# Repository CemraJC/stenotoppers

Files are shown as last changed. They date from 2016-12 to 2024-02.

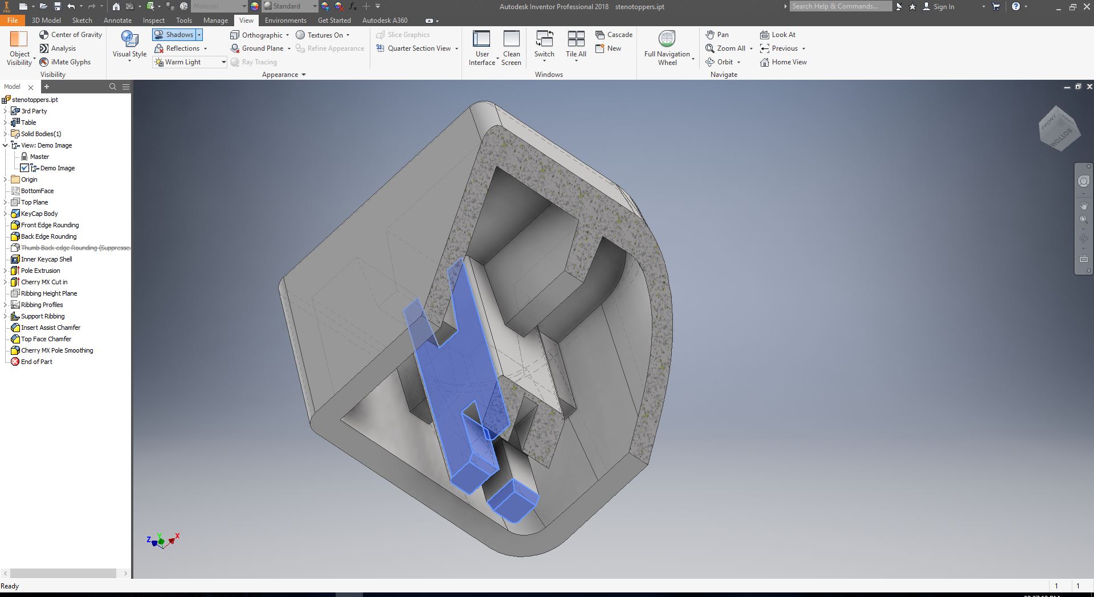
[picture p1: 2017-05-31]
images/autodesk-inventor-editing-demo.jpg

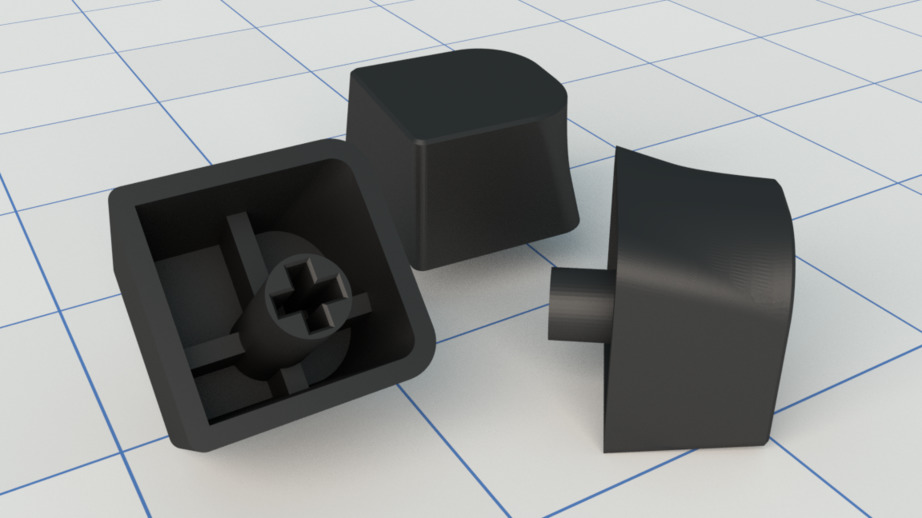
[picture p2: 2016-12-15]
images/stenotopper-closeup.jpg

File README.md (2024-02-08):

# StenoToppers

> Convert your keyboard into a stenotype!  
> *Version 1.2.0*

Demonstration of StenoToppers (Render)

## [Get them from the releases page!](https://github.com/CemraJC/stenotoppers/releases)

## Hall of Fame

[Visit the hall of fame!](https://github.com/CemraJC/stenotoppers/wiki/StenoToppers-Hall-of-Fame) Submit your own prints through the Issues tab, or by editing the Wiki directly!

## *Update*

The StenoToppers keycap set now includes number bar (numbar) keys (since version 1.1.0). These keys are much like normal keys, but they fit on the same level as the StenoToppers and sit nice and close together.

Two additional print assemblies have been made available - one for just the numbar keys, and another for the full set *including* the numbar keys.

### Preface

This repository contains the 3D design files for the "StenoToppers", including and [a detailed CAD drawing][cad-pdf] and 3D models. The branch "[generic-models][generic-branch]" has files (in STL format) that should work with any proper 3D modeling software (such as [AutoDesk 123D][123d-editor] or [Blender][blender]). This branch (master) contains the part files and assemblies for [AutoDesk Inventor 2016][inventor], from which the STL files are derived.

Note that StenoToppers are designed for use with a mechanical keyboard that supports [N-key rollover (NKRO)][nkey], alongside the fantastic open source [Plover][plover] software. If you're interested in learning more about *typing at the speed of thought*, see the [Plover Blog][plover-blog]. 

**If it all seems too hard:**<br> 
3D model and printing work is currently fiddly and time consuming. If you want a quicker solution that is guaranteed to work on any steno-ready keyboard, then we heartily recommend the [Laser-Cut Keytoppers][keytoppers] ($20 USD + $Shipping) from the [Plover Store][plover-store]<sup>[1](#not-a-sponsor)</sup>. These are secured to existing keycaps with some sturdy "adhesive foam" and are reportedly easy to set up.

It is left as an excercise to bored DIY steno-enthusiasts to design and manufacture injection-moulded parts, which will inherently fit better and feel lighter.

**If it all seems too easy:**<br>
As this is an open source project, you are very welcome (and encouraged) to make and sell StenoToppers by your own means, under the terms of the license. In short, just make sure clients are aware that the project is open source and that they retain the same freedom to use this project as you do.

Anyway, on with the show.

## What are StenoToppers?

StenoToppers are a set of custom 3D printed keycaps which convert a mechanical keyboard into a stenotype look-alike. They are designed to fit any keyboard with Cherry MX keyswitches or any "identical" Cherry MX clone. 

The whole point of these keycaps is to slightly raise, compact and align the top two rows of keys (making it easier to chord them) and move the thumb-keys comfortably above the space-bar and into a more ergonomic position. Without StenoToppers, it is harder to press two keys with one finger and thumbs can become *very* sore trying to avoid the spacebar all the time.

Demonstration of StenoToppers (Real)

### A Note on Key Spacing

Notice how StenoToppers make the keys look a fair bit wider than normal keycaps. This is because StenoToppers utilize almost the entire keycap base to allow multiple keys to be pressed at once. On a QWERTY keyboard, pressing multiple keys at once is often undesirable, so keycaps heavily taper off to provide substantial space around them - too much space for speedy stenography. 

Also, note that although they line up horizontally (ortholinear), your keyboard is likely to have a non-standard slope angle to the base. This means that and keys are likely to be _vertically_ offset by two millimeters, and may collide. This shouldn't affect stenography in any noticeable way once [fitted properly][fitting-guide].

Top down of StenoToppers

For more detailed dimensions and specifications, check out the [drawing PDF][cad-pdf].

### Types of StenoToppers

Note that there are *four* variants of the keycap: standard, large, small and thumb. The standard keycaps are in majority and line up most of the top row's keys. The small and large variants are meant to go on the end of each row (in the right place, of course) so the rows match up with existing keys that are still staggered (like enter and tab). The small and large variants are required so the end of each row fits, but if the keyboard is otherwise empty of keys, they are optional. Thumb keys have no offset on the keycap stem, so they will fit in straight up-and-down.

# How to get StenoToppers

StenoToppers **are 3D printed items.** If you are lucky enough to have access to a 3D printer, then you can likely print these off yourself for very little cost. For the rest of us normal people, online services like [Shapeways][shapeways-store] and [Sculpteo][sculpteo] can print the models for you, albeit at a much higher cost. For even *more* money, you could even get them done in [nylon][shapeways-nylon] or [steel][shapeways-steel]! 

The models have been prepared on [Shapeways][shapeways-store], in the "Logical Store".

*Note: Try to avoid super expensive materials. The ABS and PLA materials are verified on home printers, but things like steel or aluminium are not verified to fit. See the [fitting guide][fitting-guide] for more information.*

# Printing

Printable models are available from the [generic-models][generic-branch] branch. All released versions can also be downloaded directly from the [project website][project-website] or the [Github Releases Page][github-releases].

### Print Stats:

| Full Print  | |
| :---: | :--: |
| Bounding box (Machine Space) | 130mm x 100mm x 20mm (208cm<sup>3</sup>) |
| Print mass | ~53g |
| Print material volume | ~51cm<sup>3</sup> |
| Print filament length | ~7.6m |
| Average Time | ~11.5 hours (at normal quality) | 
| Average material cost | $3 (assuming $50 for a 1kg reel) |
| Shapeways cost | Strong and Flexible, White: $60<br>Strong and Flexible, Black: $61 |

| Test Print  | |
| :---: | :--: |
| Bounding box (Machine Space) | 62mm x 40mm x 20mm (49cm<sup>3</sup>) |
| Print mass | ~10g |
| Print material volume | ~9.6cm<sup>3</sup> |
| Print filament length | ~1.4m |
| Average Time | ~3.2 hours | 
| Average material cost | 60 cents |

| Single Keycap  | |
| :---: | :--: |
| Bounding box (Machine Space) | 130mm x 100mm x 20mm (208cm<sup>3</sup>) |
| Print mass | ~2g |
| Print material volume | ~1.9cm<sup>3</sup> |
| Print filament length | ~28 cm |
| Average Time | ~40 mins | 
| Average material cost | 12 cents (i.e. Negligible) |

### Custom Keycap Sets

Sometimes, the "final" and "test" pre-compiled packages aren't what you're looking for. If, for example, you want to print a set of 350 standard keys (not sure why) then you'll need to make a custom assembly. If you're unfamiliar with 3D printing or 3D modelling, this may seem like a difficult task, however with tools such as [AutoDesk Meshmixer][meshmixer] or [Meshlab][meshlab] this task is relatively easy. When you download the models, you will have access to the individual keycap models. For a full keyboard, you should be printing **2 large, 2 small, 4 thumb and 18 standard stenotoppers**.

There are guides on how to merge STL files all over the place. Here is just a couple:

* [Meshmixer: Combining Models](http://www.instructables.com/id/Meshmixer-Combining-Models/)
* [Merging STL Files](https://edditiveblog.wordpress.com/2015/01/02/merging-stl-files/)
* [Editing and merging STL files. How-to and an offer. Any interest?](https://groups.google.com/forum/#!topic/inmoov/k4kzPOrsuzs)

### Pre-print checklist

<input type="checkbox"> Line width is close to (or less than) 0.5mm
<input type="checkbox"> Layer height is close to (or less than) 0.3mm
<input type="checkbox"> Printing with the top of the keycap(s) facing the print bed
<input type="checkbox"> Using a raft to avoid "elephant's foot"
<input type="checkbox"> Using 60% infill or above (for final-quality print)
<input type="checkbox"> Have at least 9m of filament on the spool.

### Minimum 3D Printer Specs

* Min Print bed size: 130mm x 100mm x 20mm for full print
    - Theoretically, you could make do with a 20mm x 20mm x 20mm if you were willing to do multiple prints.
* Max Layer height (for a good-quality print): 200 microns (0.2mm)
* Max Extrusion width: 500 microns (0.5mm) - aim for lower (0.4 or 0.3)

### An Important Note on Clearances

Because the Cherry MX stem is a standard size, it is important that the keycaps are printed so they fit snugly. For this reason, proper printer calibration is very important. Keyboards may vary, but ideally they will have the same key spacing and stem dimensions.

It's more complex than it sounds to get true-to-model dimensions, because different printers have varying tolerances (i.e. the printer will affect how much the printed object is different from the model). This is because things shrink as they cool. Some printers change their cooling settings or do over-extrusion in an attempt to correct this. These factors mean that a feature of the model can potentially end up smaller (rarely larger) in the print than it was in the 3D model. For tight fits like the Cherry MX stem, this contraction actually stops the keycap from fitting on the stem. 

All that is to say that an improperly calibrated printer has some consequences for this kind of model. Overall, you should expect to make minor adjustments to your printer to make sure it's printing true-to-model. 

If you don't want to muck around with your printer, then never fear - see the [fitting guide][fitting-guide] for ways to get the StenoToppers properly mounted on your keyboard.

## Model Customization (Advanced, optional)

The models are designed to be customized easily. Luckily, the majority of keyboards are designed to have a standard layout and spacing - so typists have consistency - which means that the default models *should* work fine, although you should definitely *do a test print* before printing all 26 keycaps.

Because the StenoToppers were designed in AutoDesk Inventor, we recommend using Inventor to modify them for your keyboard as well. See [this document][inventor-customization] for a very brief tutorial.

Demonstration image of Editing the 3D model with AutoDesk Inventor

However, for normal people who do not have access to software such as
AutoDesk Inventor, there are '.stl' models available for use in free modeling programs such as [AutoDesk 123D][123d-editor], [Blender][blender] or [MeshLab][meshlab]. Please see the "[generic-models][generic-branch]" branch for these. You will need to search for specific instructions on how to use your chosen mesh editor in order to edit the models. Obviously, if you customize a keycap, you will need to make your own print assembly.

Unfortunately, editing STL files can be a pain - especially when you need precision. If you have any suggestions for how to make the project more editable, be sure to open an issue on Github.

Demonstration image of Editing the 3D model with Blender

## A Word On Financial Contributions

The StenoToppers project does not accept voluntary financial support directly. Instead, all financial contributions towards this project should be made out to the [Open Steno Project][plover-donate]. Note that the StenoToppers team is not in any way affiliated with Plover or the Open Steno Project - it is simply that without them, StenoToppers would not have any reason to exist.

[Click for the Plover project donation page][plover-donate]

## Footnotes

[<a href="#not-a-sponsor">1</a>]: The StenoToppers team has no affiliation with any of the 3rd party projects or services mentioned in this document.

<!-- Link table, sorted by category -->

[inventor]:http://www.autodesk.com.au/products/inventor/overview
[inventor-customization]:https://github.com/CemraJC/stenotoppers/blob/master/docs/Customization%20with%20Inventor.md
[blender]: https://www.blender.org/download/
[123d-editor]: http://www.123dapp.com/design
[meshlab]: https://sourceforge.net/projects/meshlab/
[meshmixer]: http://www.meshmixer.com/

[fitting-guide]: https://github.com/CemraJC/stenotoppers/blob/master/FITTING-GUIDE.md

[generic-branch]: https://github.com/CemraJC/stenotoppers/tree/generic-models
[project-website]: https://cemrajc.github.io/stenotoppers/
[github-releases]: https://github.com/CemraJC/stenotoppers/releases
[cad-pdf]:https://github.com/CemraJC/stenotoppers/blob/master/drawings/base-keycap_cherrymx.pdf

[plover]: http://stenoknight.com/wiki/Getting_Started#Installing_Plover
[plover-blog]: http://plover.stenoknight.com/
[plover-store]: http://plover.deco-craft.com/
[plover-donate]: https://www.openstenoproject.org/donate/
[keytoppers]: http://plover.deco-craft.com/shop/view_product/Laser-Cut-Steno-Keys-Kit
[nkey]: https://en.wikipedia.org/wiki/Rollover_(key)

[sculpteo]: https://www.sculpteo.com/en/
[shapeways]: http://www.shapeways.com/
[shapeways-store]: https://www.shapeways.com/shops/logical-store?section=Stenography+and+Plover&s=0
[shapeways-steel]: http://www.shapeways.com/materials/steel
[shapeways-nylon]: http://www.shapeways.com/materials/strong-and-flexible-plastic

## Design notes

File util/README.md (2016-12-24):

This directory contains a script to run MeshLab server on a directory of STL files. The MeshLab script (.mlx) cleans and decimates (simplifies) the parts making them smaller and easier to handle.

Use only if you have MeshLab installed and are generating STL files. You will also need a Linux CLI.

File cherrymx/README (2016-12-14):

This folder contains models designed for the Cherry MX keyswitch design.
Note that these models are also suitable for Cherry MX variants (such as kailh).

For printing, please see the 'generic-models' branch of this repository.

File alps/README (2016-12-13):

This folder would contains models adapted for the ALPS keyswitch design.

Note that these models, although potentially useful, do not yet exist because
it was decided that Cherry MX switches are more common. Regardless, if a serious
need for ALPS switch variants of the StenoToppers arises, then the models will
go here.

This project is structured to allow for addition of alternative
keyswitch affixing systems.

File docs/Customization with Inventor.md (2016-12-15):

# Customizing the StenoToppers with AutoDesk Inventor

It is very easy to adjust key dimensions of the StenoToppers if you have access to AutoDesk Inventor. All the dimensions (parameters) are linked to the top-level "parameters.xlsx" file, so simply follow these steps to change one:

* Open the "parmeters.xlsx" file
* Find the parameter you want to change (they are clearly marked / described)
* Change it to your desired value (note that changing something too much may cause problems with the model, so modify only within reason)
* Save the spreadsheet
* Open the "stenotoppers.ipt" file in the "cherrymx" directory, using Inventor
* Navigate to `Manage > Parameters Panel > Parameters` (looks like *f<sub>x</sub>*) 
* With the parameters window open, click the "Update" button on the 2nd bottom row. The model should change to reflect your modification of the spreadsheet.
* If everything looks normal, close the parameters window and the spreadsheet.
* Export each iPart variant to STL format (see below)

### Exporting to STL

The StenoToppers model is what Inventor calls an "iPart", although you may have heard them called "Factory models" or "Factory parts". See [this tutorial][TFI-tutorial-iparts] for more information on iParts.

Because the model is an iPart, some custom code was needed to export each variant to STL. 

[TFI-tutorial-iparts]:link

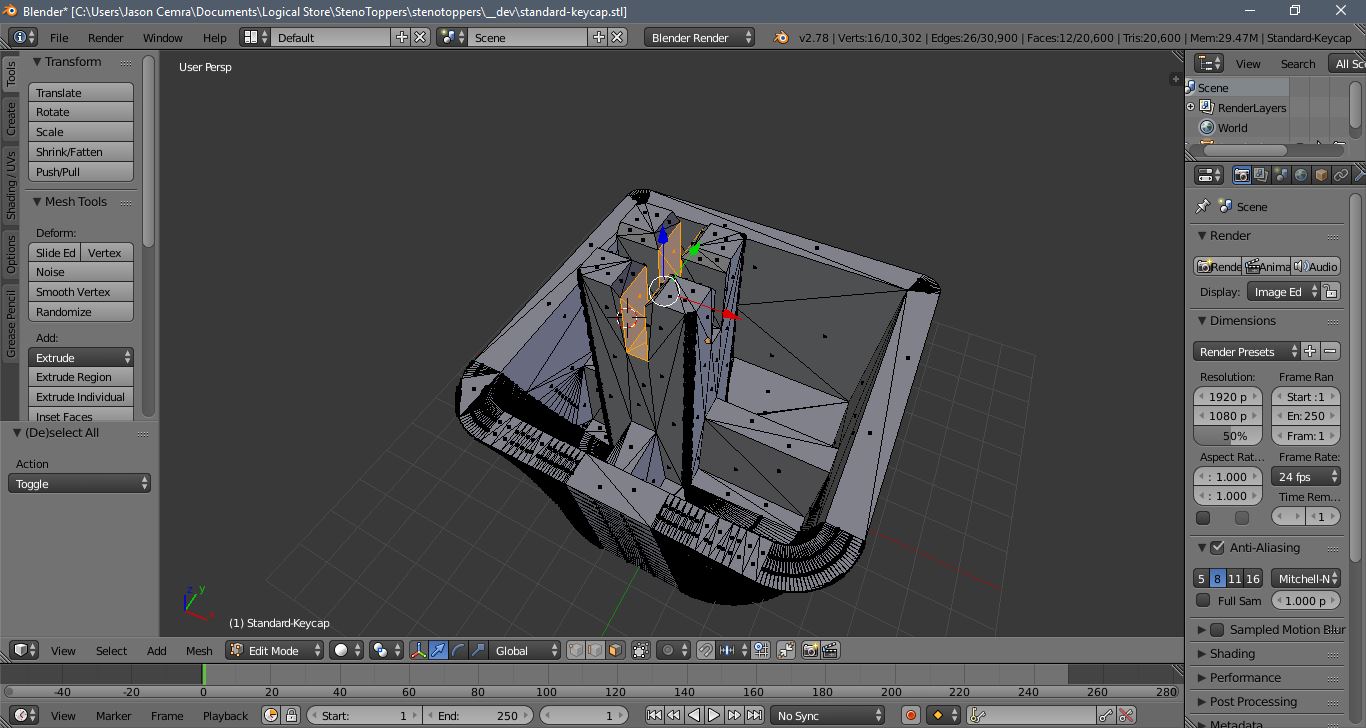
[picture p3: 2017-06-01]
images/blender-editing-demo.jpg

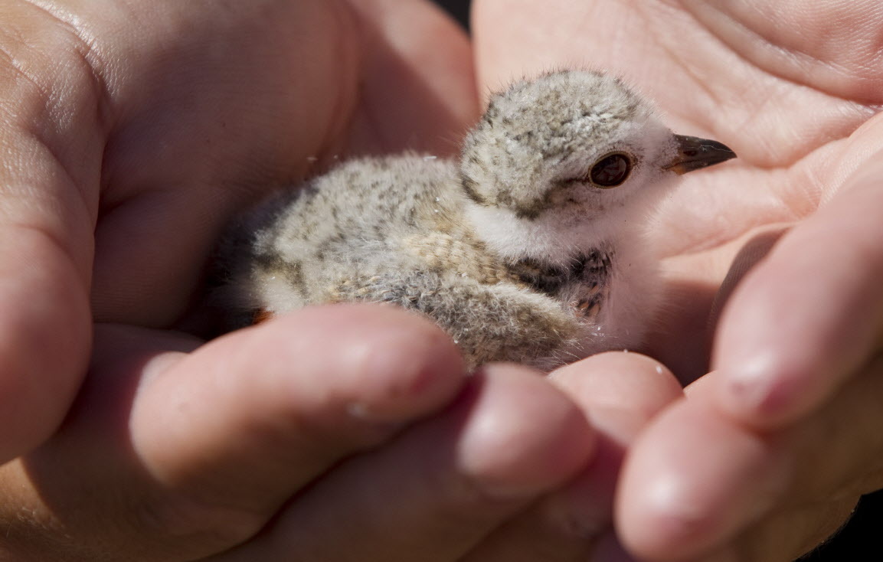
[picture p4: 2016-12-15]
images/plover-donate-image.jpg

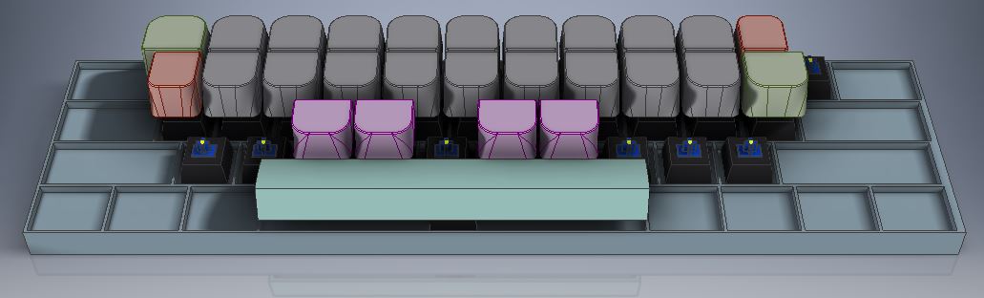
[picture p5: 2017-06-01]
images/stenotopper-demo-image.jpg

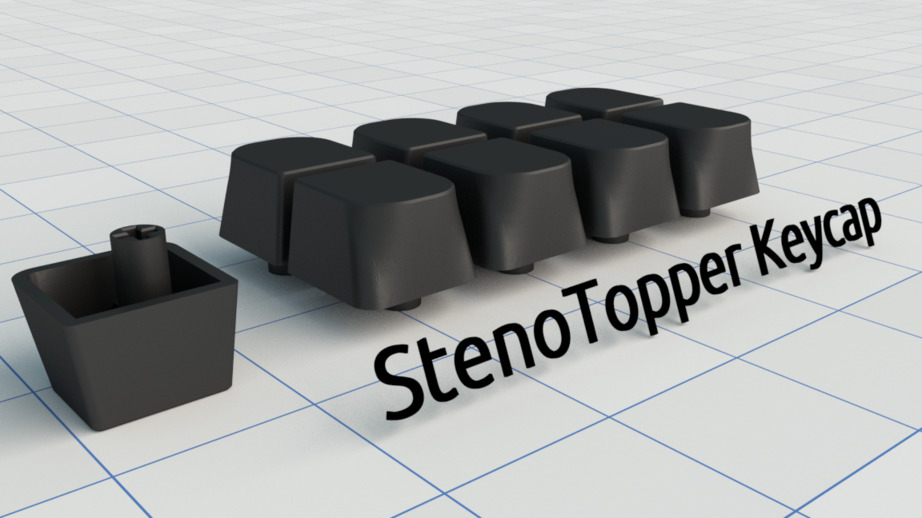
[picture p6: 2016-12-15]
images/stenotopper-render.jpg

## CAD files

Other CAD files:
drawings/stenotoppers_dimension_annotated.dwg
cherrymx/mockup-parts/cherry-mx-switch/keyswitch-base_cherrymx.ipt
cherrymx/mockup-parts/cherry-mx-switch/keyswitch-pole_cherrymx.ipt
cherrymx/mockup-parts/cherry-mx-switch/keyswitch_cherrymx.iam
cherrymx/mockup-parts/keyboard-base_standard.ipt
cherrymx/mockup-parts/keyboard-mockup_cherrymx.iam
cherrymx/mockup-parts/populated-keyboard_cherrymx.iam
cherrymx/mockup-parts/spacebar-keycap_mockup_cherrymx.ipt
cherrymx/print-assemblies/final-print-(with_numbar).iam
cherrymx/print-assemblies/final-print.iam
cherrymx/print-assemblies/numbar-print.iam
cherrymx/print-assemblies/test-print.iam
cherrymx/stenotoppers.ipt
cherrymx/stenotoppers/larger_cmx.ipt
cherrymx/stenotoppers/numbar_cmx.ipt
cherrymx/stenotoppers/smaller_cmx.ipt
cherrymx/stenotoppers/standard_cmx.ipt
cherrymx/stenotoppers/thumb_cmx.ipt
drawings/base-keycap_cherrymx.idw

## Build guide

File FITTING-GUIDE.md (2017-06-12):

# StenoToppers Fitting Guide

**Warning:** This project is not for the impatient. If you try to rush through the fitting process, you may end up breaking somthing. Although, since you're into steno, I imagine you like doing things the right way. I can assure you, StenoToppers are the "right way" to do DIY steno :wink:.

So grab a some fine wine and put on your favourite classical music. Depending on the quality of your print, the full fitting could take anywhere between 2 and 5 hours. The printer I had access to was pretty rubbish, so I believe this fitting guide covers the worst-case scenario quite well. Chances are good that your print will come out nicely.

When StenoToppers come out of the printer, they will likely not fit on your keyboard straight away. Straight off the printer, they look like this:

Messy StenoToppers

If you look closely, there's all sorts of garbage clogging up the connection mechanism:

Closeup of StenoTopper mess

If the printer isn't perfectly calibrated, and you're using a material or printing method that leaves a lot of residue behind, then there's going to be some cleanup to do. This guide is all about how you can get your StenoToppers from the images above to look like this:

Clean StenoToppers

## What you'll need

#### Needle File

You need a *very* fine needle file to clean up the stem. You should be able to get some of these cheaply if you don't already have them. Also, check to see if your friends can lend you any.

**Important:** If you have access to a Dremel (hand-held rotary bit tool), then I would highly recommend using it with a griding wheel rather than a file. Just be careful not to damage the key.

Needle files

#### Craft Knife

Just something with a sturdy blade. There's going to probably be bits of excess material on the upper part of the stem that makes the key stick if you try to press it on an angle. A knife will clean it up quicker than a file.

Craft Knife

#### Sticky Tape

Preferably high-quality. You may need this to make the key surface smooth (rather than the stepped finish from the printer). A smooth surface dramatically decreases the effects of interference.

Sticky Tape

#### Key Puller

You need to remove the existing keycaps from your keyboard. My keyboard came with the one below. I highly recommend using one of these, because trying to remove standard keycaps with fingers or a knife generally ends up with things being broken. A key-puller *may* not work with the StenoToppers, because they are much wider. They are tall enough, however, that you should be able to grip them with your hands.

Key Puller

## Procedure

For each key, you're doing the same basic thing: Cleaning and fitting. There's three basic things that, when done properly, will complete the fit and finish of the key.

1. Remove excess stem material
2. Fit keycap to a keyswitch
3. Make required surfaces smooth

**Important note:** If you're going to be doing this with needle files, I recommend that you spread the work out over a few days - to avoid your hands cramping up. I did all the filing in one hit (roughly 3 hours), and it took a further hour for my hands to fully recover.

With that out of the way, I'll go through each step for a standard stenotopper, and you can follow it for the rest.

### 1. Remove excess stem material

To get rid of the garbage the printer left behind, there's two main techniques. For the big stuff, you can try (gently) scraping it off with a craft knife:

Using knife for rough removal

Be sure to cut away from yourself, or use a grip that gives you *very* tight control over the blade. It's easy to slip on small parts like this.

Once the big stuff is removed, you'll likely need to use a needle file to clean up the inside of the stem and under the key:

Using file for clean up

Make sure you also target any waste on the *outside* of the stem, because this can affect how smoothly the key operates. It's hard to see, but if you feel it catch on the way down, then you probably just need to file down the outer faces.

Inner-waste highlighted

### 2. Fit keycap to a keyswitch

First, pull a keycap off your keyboard (use a key-puller please) and try to fit the stenotopper. Chances are, it won't fit. Don't force it - just take it off and do a *tiny* bit of filing on the inside. Remember, it only takes a difference of about 0.4 mm to go from too-tight to just-right. Be patient, you'll get the hang of it.

If you have removed all the waste material, the key should fit snugly and press in without catching - at any angle. If you use your finger to wobble the key around, it shouldn't move much more than 5 mm in any direction.

There may be a *tiny* gap between the top of the inside of the stem, and the top of the keyswitch. This is normal, and is meant to provide a bit of extra material in case the print comes out a bit off.

Front close up on switch

### 3. Make required surfaces smooth

When pressing the keys down, they will deflect a bit and probably rub against the key behind it (if there is one). This is expected, and will likely occur if your keyboard has an angled backplane. The solution is quite simple - just put some tape across the back of the key, to make it smooth.

Applying Sticky Tape

Sanding the back of the key is also an option, but this takes a fair bit more time - especially considering how many keys there are.

## And you're done!

Top down view

Once you have repeated the process for each key, you will have a full set of StenoToppers. Set aside about 5 hours to do this - it takes a while, but it's worth it for a comfortable DIY stenotype.

You may notice that the keys feel a bit heavier than normal. This is a by-product of the thickness of 3D printed parts and is unavoidable without using different manufacturing techniques. Personally, I like the heavier feel. It makes the keys seem like they're solid, and *really* doing something. Sort of like a heavy watch. Of course, your mileage may vary with this.

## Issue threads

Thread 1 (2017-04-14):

ready for standard use?

gabrielqv, 2017-04-14:
So when do you think the project will reach 1.00, didn't find any info of why you said it was not recommend for use yet.

CemraJC, 2017-06-01:
Sorry things are taking so long - there were many problems with shipping test parts over (mostly courier mishandling or lost in post).  I have only just received the final test print, and am working on the final release documentation.

You should expect the final release within 2 weeks.

Closed 2017-06-03.

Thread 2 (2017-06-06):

Generate smaller STL files that will print faster?

ddrscott, 2017-06-06:
Is it possible to generate smaller sets of STI files? My local library has a 6 hour print maximum.
Maybe group by left and and right and final?
I don't have Autodesk Inventor to attempt it myself.

Thanks

CemraJC, 2017-06-12:
Fear not! You do not need AutoDesk Inventor to do this.

As you are aware, there are individual STL files provided for each type of keycap. If, I assume, you want to be sending two print jobs to the printer to stay under the 6 hour maximum, then I would recommend using software such as [AutoDesk Meshmixer](http://www.meshmixer.com/download.html) or [meshlab](http://www.meshlab.net/) to merge the single-keycap STLs into each job as you desire.

As this is quite a specific scenario, hopefully you can understand why I would like you to do this yourself. In short order, I will add a section to the Readme with my above comments, for future users.

Closed 2017-06-17.

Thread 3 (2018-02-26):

Orthographic layout

brennenawana, 2018-02-26:
Would be great to have stenotoppers made for orthographic keyboard layouts like the Plank. I guess that would basically mean removing the staggered offset. Great work, thanks so much!

CemraJC, 2018-03-01:
Not a bad idea! I might get around to making a variation of the existing models, should be easy enough. I'll put it on my long-term todo list for now.

wrongPaul, 2018-04-25:
I literally just came here to open the same issue, has anyone made any progress on this? If not (or possibly even if they have) I'll start working on porting these over

nadavwr, 2020-10-10:
Maybe we can just print thumb toppers only for all fingers? I tried to give a closer look at the 3d model, and seems to me like the north-facing side is a bit more slanted (making chording a bit harder)—am I imagining this?

AndersonTorres, 2020-12-08:
Another one!

I bought an ortholinear keyboard and I would like to try steno on it.

designbybeck, 2020-12-08:
Very nice Anderson, I'm a newbie as well. Only started following this
project because I was interested in plover and steno stuff and wanted to
look into making my own.

On Mon, Dec 7, 2020 at 10:08 PM Anderson Torres <notifications@github.com>
wrote:

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

canuckkat, 2021-07-26:
> Not a bad idea! I might get around to making a variation of the existing models, should be easy enough. I'll put it on my long-term todo list for now.

Any luck on porting them over? I wish I knew enough to help. :(

BoxingLaunch, 2022-01-31:
Has anyone made any progress on this? Would love some ortho keycaps!

AndersonTorres, 2022-01-31:
Maybe I should talk with a CAD guru or something like.

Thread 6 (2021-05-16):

My Stenotopper Setup

JeffersonDing, 2021-05-16:
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

CemraJC, 2021-06-16:
Hey man, that's awesome!

I'll add you to the hall of fame.

I'll leave this "issue" open, so if anyone else stumbles across this, they can [find the link to the hall of fame](https://github.com/CemraJC/stenotoppers/wiki/StenoToppers-Hall-of-Fame).

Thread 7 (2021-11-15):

Stenotoppers and POM Jellies

DrMeiji, 2021-11-15:
Here is my board with the stenotoppers installed, printed at my university's library. The board is a GK64X with gateron black switches and strawberry POM jelly alpha numerals.

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

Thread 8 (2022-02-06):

My StenoTopper set - Just learning

RunningUtes, 2022-02-06:
Just thought I would modify the STL file and create a StenoTopper for learning. Printed on a Prusa MK3s in 4h.
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

I modified the stl file so there was no need to file the keys. They went on the key switches straight off the printer.

CemraJC, 2023-02-27:
Looks awesome!

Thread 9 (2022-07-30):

Stems snapping

FrocketGaming, 2022-07-30:
Curious if I'm doing something wrong on the standard prints for these. Printed two at .15mm and both of them had the stem legs flair out and snap off when trying to install onto halo clears and gateron yellows.

I really want to use these on the board I'm building.

Monniasza, 2023-07-24:
I've had this issue too at #12

Monniasza, 2023-08-17:
Here are improved keycaps at Thingiverse:
Older design:  https://www.thingiverse.com/thing:3167887
Newer design: https://www.thingiverse.com/thing:3208321

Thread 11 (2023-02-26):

Feature request: More accessible option.

Roskott, 2023-02-26:
[Solid Steonotoppers.zip](https://github.com/CemraJC/stenotoppers/files/10834360/Solid.Steonotoppers.zip)

This is what I did to make the Toppers so that I can pull them on and off without much issue, thus not having to devote my daily driver keyboard to existing solely for plover, or have to slowly pull and replace the keycaps to more easily use the program.

Each key sits on top of a cherry mx keycap, a loose amount of string runs through all four rows, loose enough to not interfere with the key presses, but enough that the entire lot can be pulled off all at once without much issue. To keep each of the keys seated properly on the keycaps, a small amount of silicone was spread around the inner lip of the cherry keycap portion to act as a nonslip surface to keep the keys from sliding or popping off at release of the key.

To slice these on SuperSlicer I enabled the Arachne perimeters. I used a negative volume cube with each of the keys to hollow out the existing stem, and reduce the weight. 2 2mmx30mm negative volume cylinders were used parallel to the xy plane intersecting at the midpoint of the cherry key stem to facilitate the string.

I am very new to 3d drafting, so this is little more than 3 models stuck together, but it is a start. I noticed that the keys that are to be placed on the qwerty row are far more stable than the others, for the numbar this was a simple matter of turning them 180deg around, but all keys on the asdf row as well as the vowel keys would need to be reworked. I am working on that now, as well as making it so that the print head will not be printing onto nothingness. for several layers.

My set are being printed into PETG with a 0.4 nozzle at 0.24 layer height.

Now would be a good time to also say that you should look around at your local libraries to see if they have access to a 3d printer. I promise it will be significantly cheaper than the Shapeways method, and most libraries with exhaustively work towards helping you get to where you need to be with this skill.

Version0.2 of this idea will rectify "newbie" model issues
Version0.3 will reduce the height and thus material
Version0.4 will hopefully be a more elegant final version someone will find useful.

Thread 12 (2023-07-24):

Issue with stems

Monniasza, 2023-07-24:
The stems in StenoToppers are fragile, unlike mass produced keycaps. I've alredy broken several keycaps due to this flaw
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

On the top is a mass produced Strike Battle Spectra keycap, on the bottom a StenoTopper. Notice how the StenoTopper does not cover the switch stem fully, but the default keycaps do.

CemraJC, 2024-02-08:
Unfortunately that's a limitation of the design - there's as much plastic in there as possible, but if there was any more (or a surrounds) then it makes the walls too thin and they're difficult to print.

3D printers have gotten a lot better than when the keycaps were originally designed, so potentially reducing the layer height and using PETG could help? If you or someone else can come up with a design that manages to make a slot surrounds (a la OEM keycap) and still fit the tolerance of the manufacturing process, then I'll happily merge a PR for it!

Closed 2024-02-08.

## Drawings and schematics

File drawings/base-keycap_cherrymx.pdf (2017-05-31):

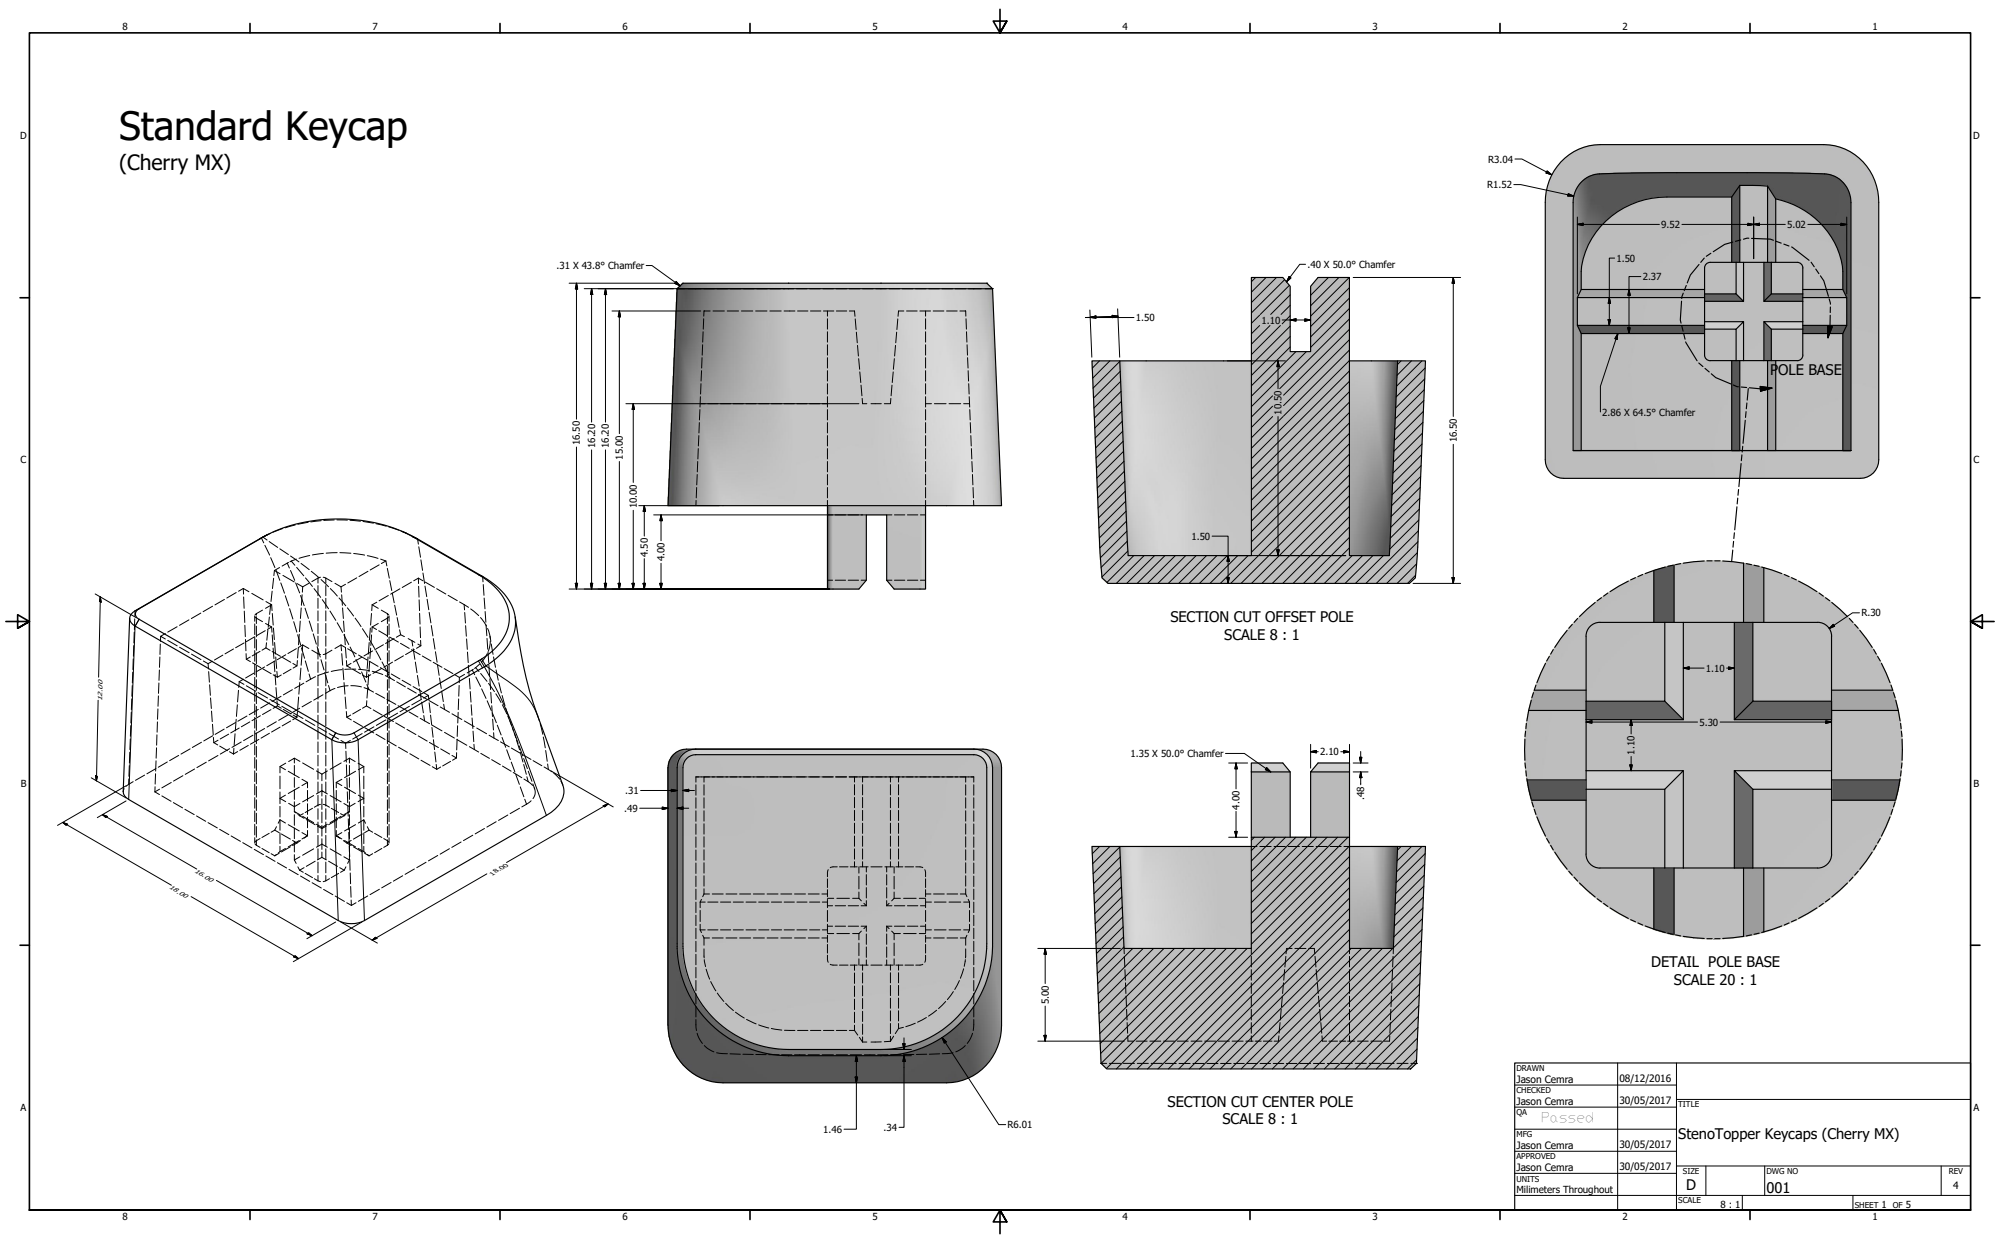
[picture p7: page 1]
SCALE 8 : 1; POLE BASE; Standard Keycap; (Cherry MX); 1.35 X 50.0° Chamfer; .31 X 43.8° Chamfer; .40 X 50.0° Chamfer; 2.86 X 64.5° Chamfer

SECTION CUT OFFSET POLE

DETAIL POLE BASE
SCALE 20 : 1

DRAWN Jason Cemra | 08/12/2016

CHECKED Jason Cemra | 30/05/2017

SECTION CUT CENTER POLE

TITLE
StenoTopper Keycaps (Cherry MX)

QA Passed

MFG Jason Cemra | 30/05/2017

APPROVED Jason Cemra | 30/05/2017

SIZE D | DWG NO | REV

UNITS Milimeters Throughout

SCALE | SHEET 1 OF 5

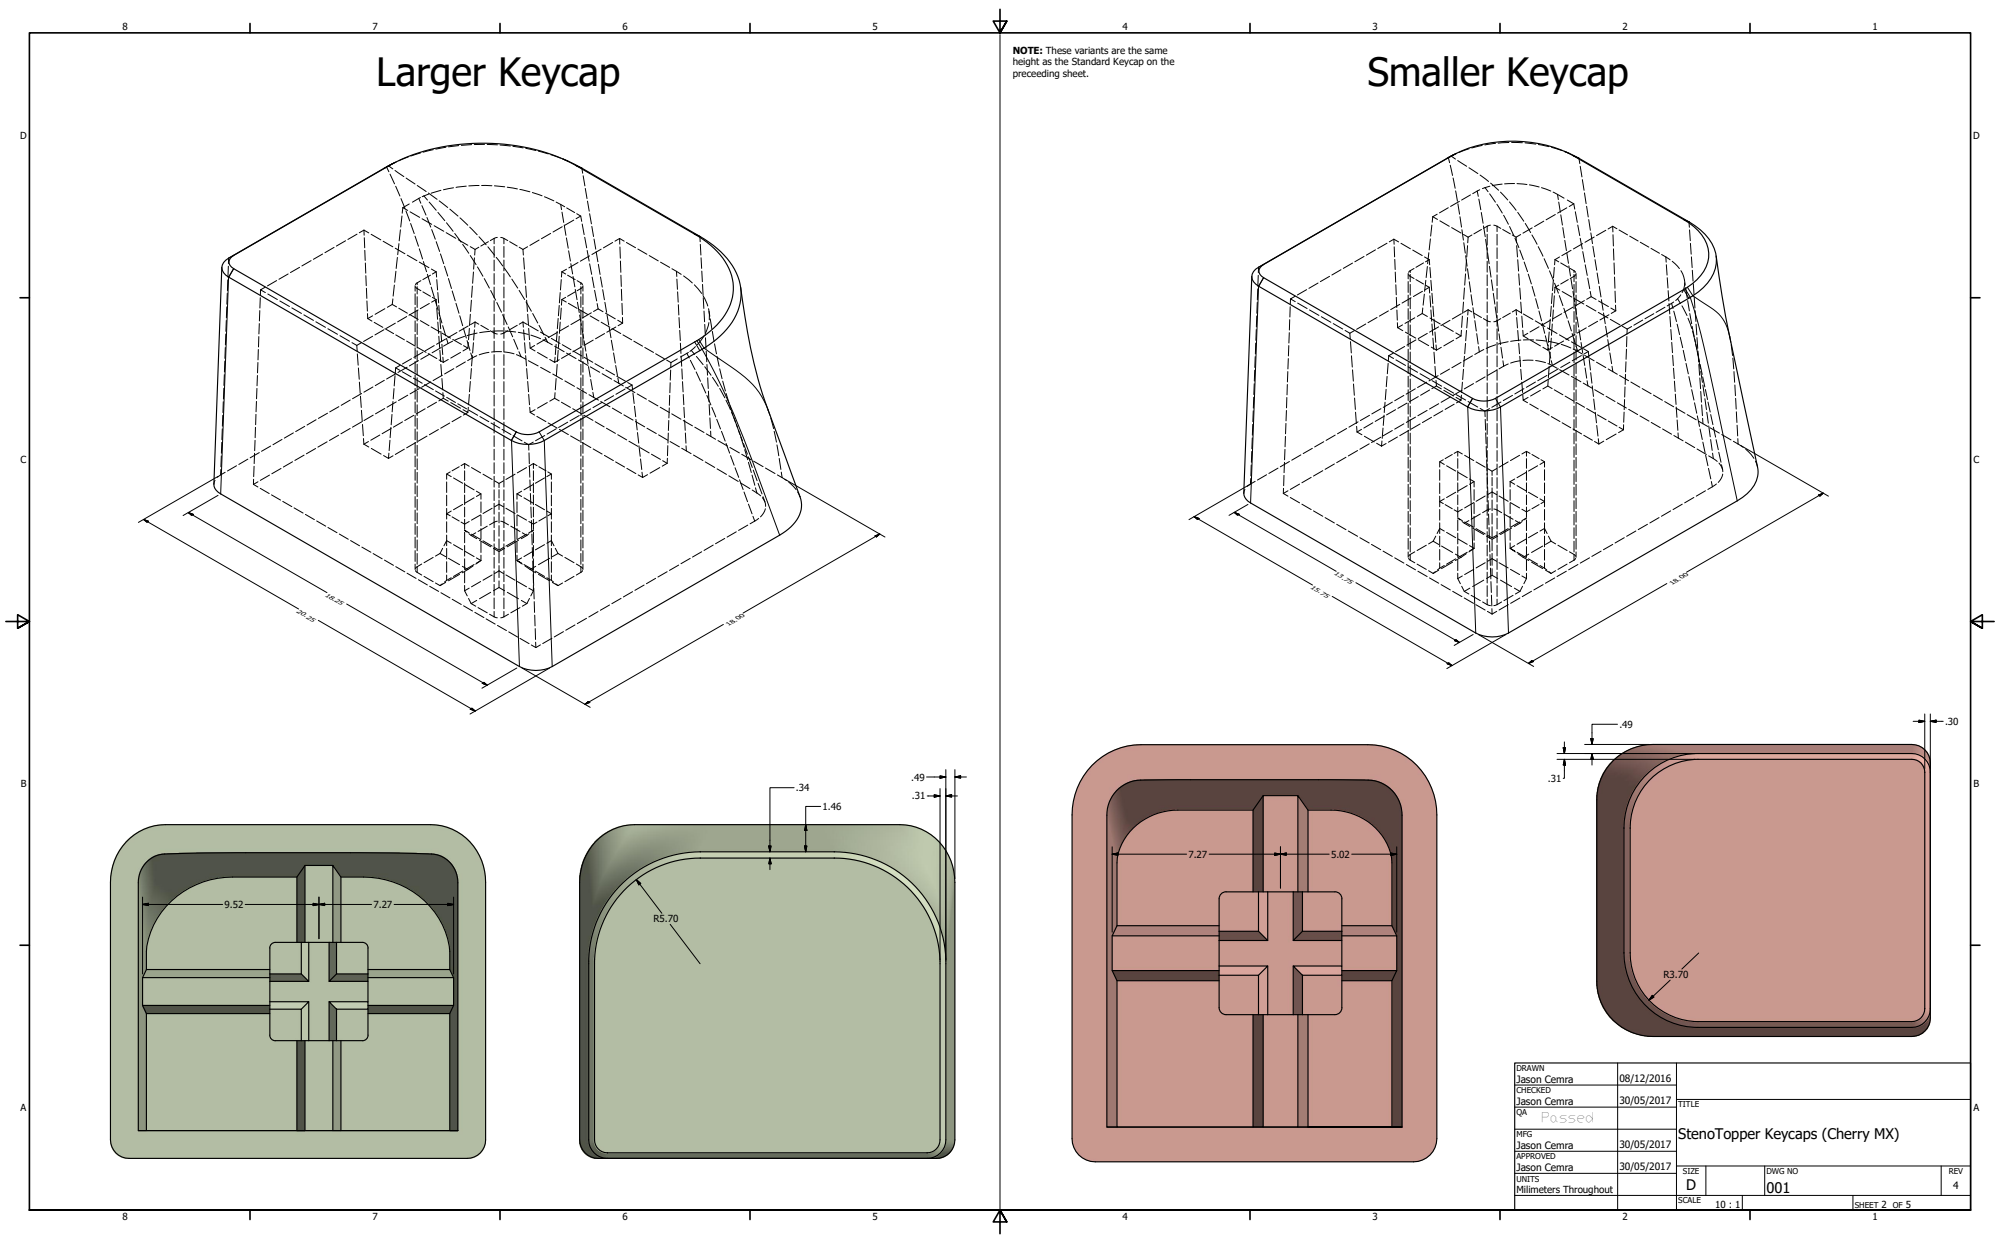
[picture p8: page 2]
Larger Keycap; Smaller Keycap

NOTE: These variants are the same
height as the Standard Keycap on the
preceeding sheet.

DRAWN Jason Cemra | 08/12/2016

CHECKED Jason Cemra | 30/05/2017

TITLE
StenoTopper Keycaps (Cherry MX)

QA Passed

MFG Jason Cemra | 30/05/2017

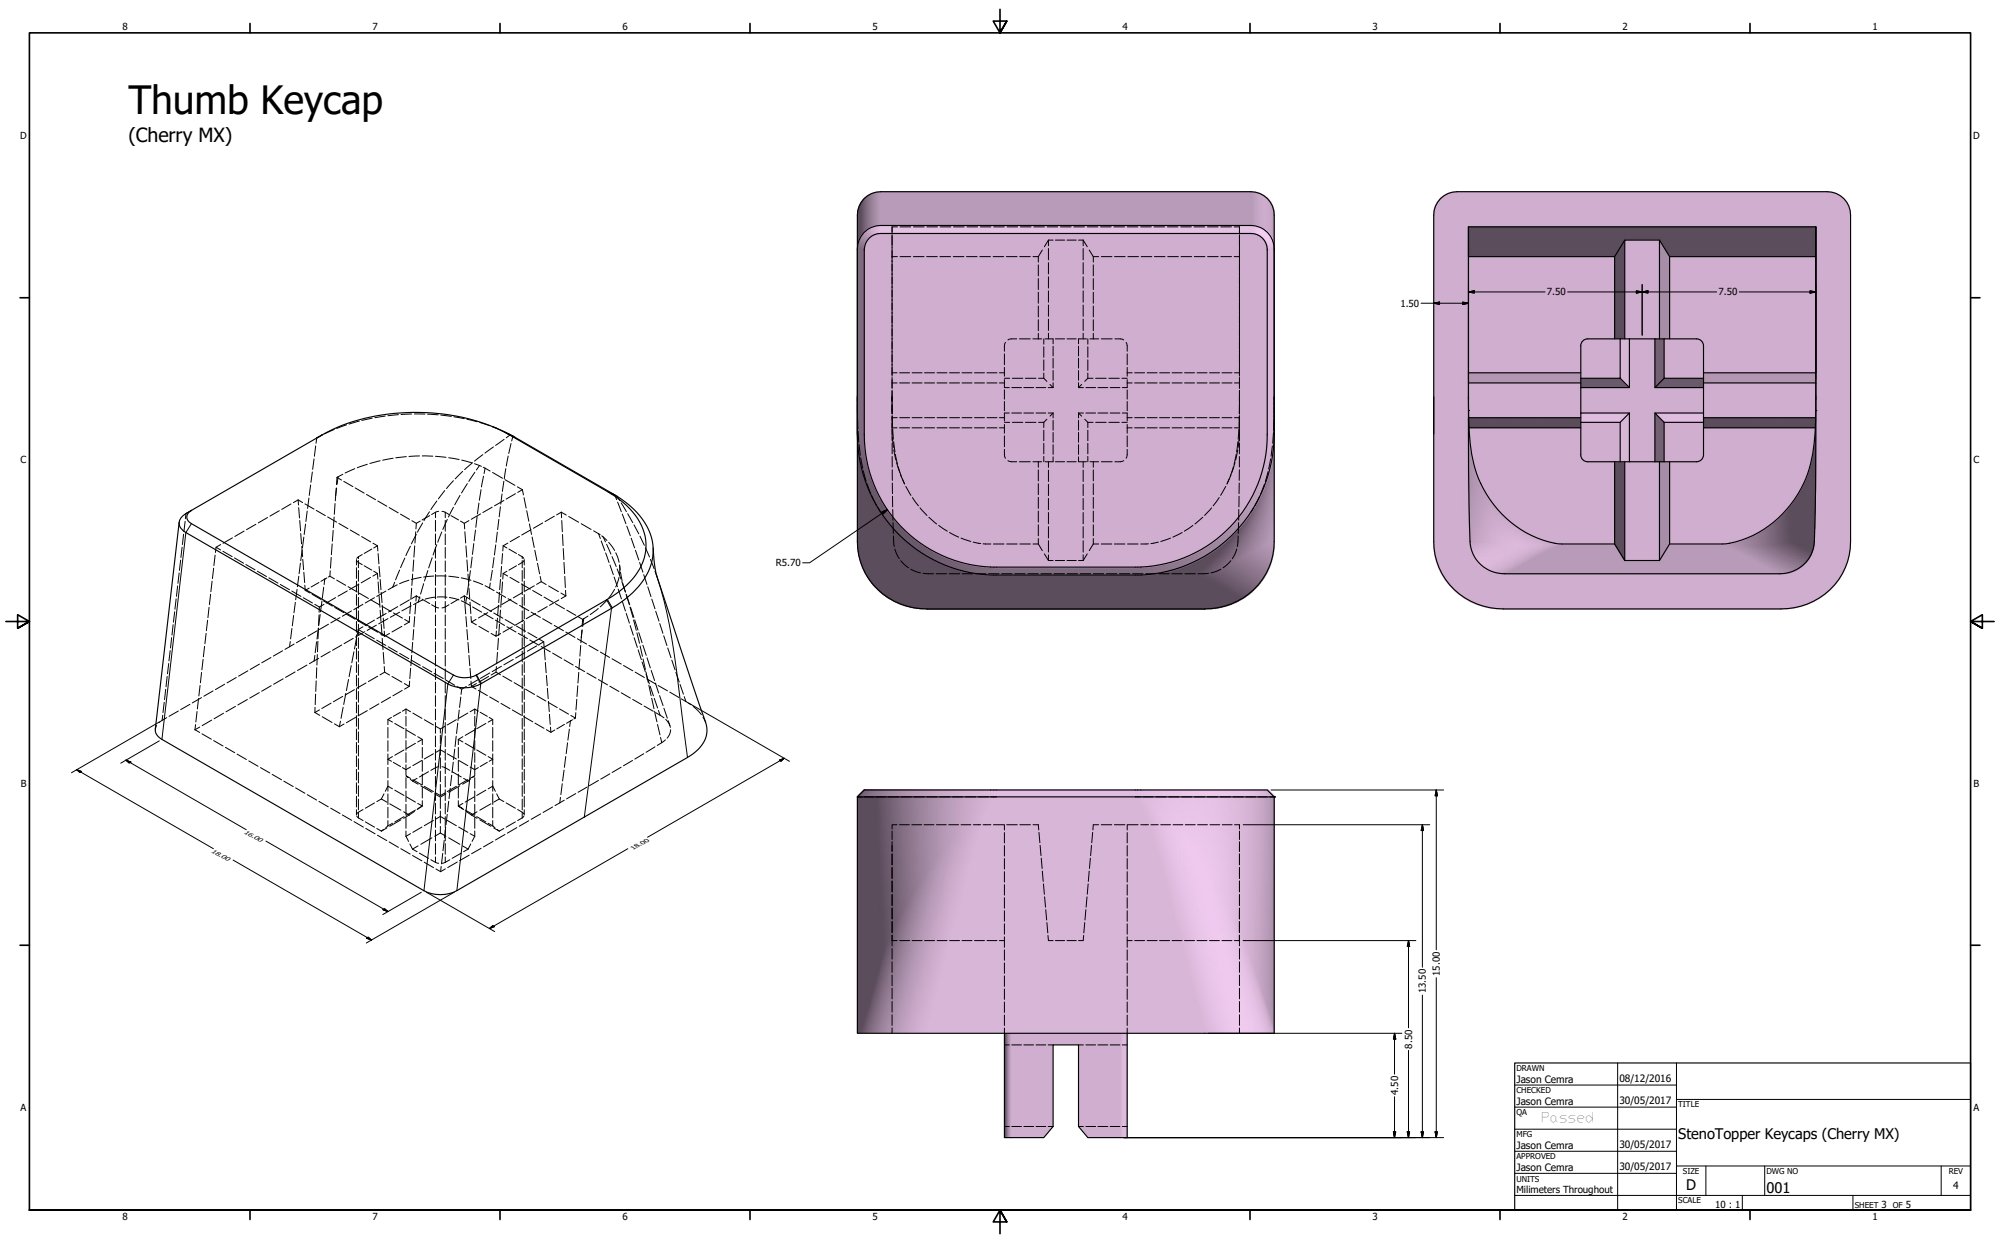
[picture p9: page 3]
Thumb Keycap; (Cherry MX)

DRAWN Jason Cemra | 08/12/2016

CHECKED Jason Cemra | 30/05/2017

TITLE
StenoTopper Keycaps (Cherry MX)

QA Passed

MFG Jason Cemra | 30/05/2017

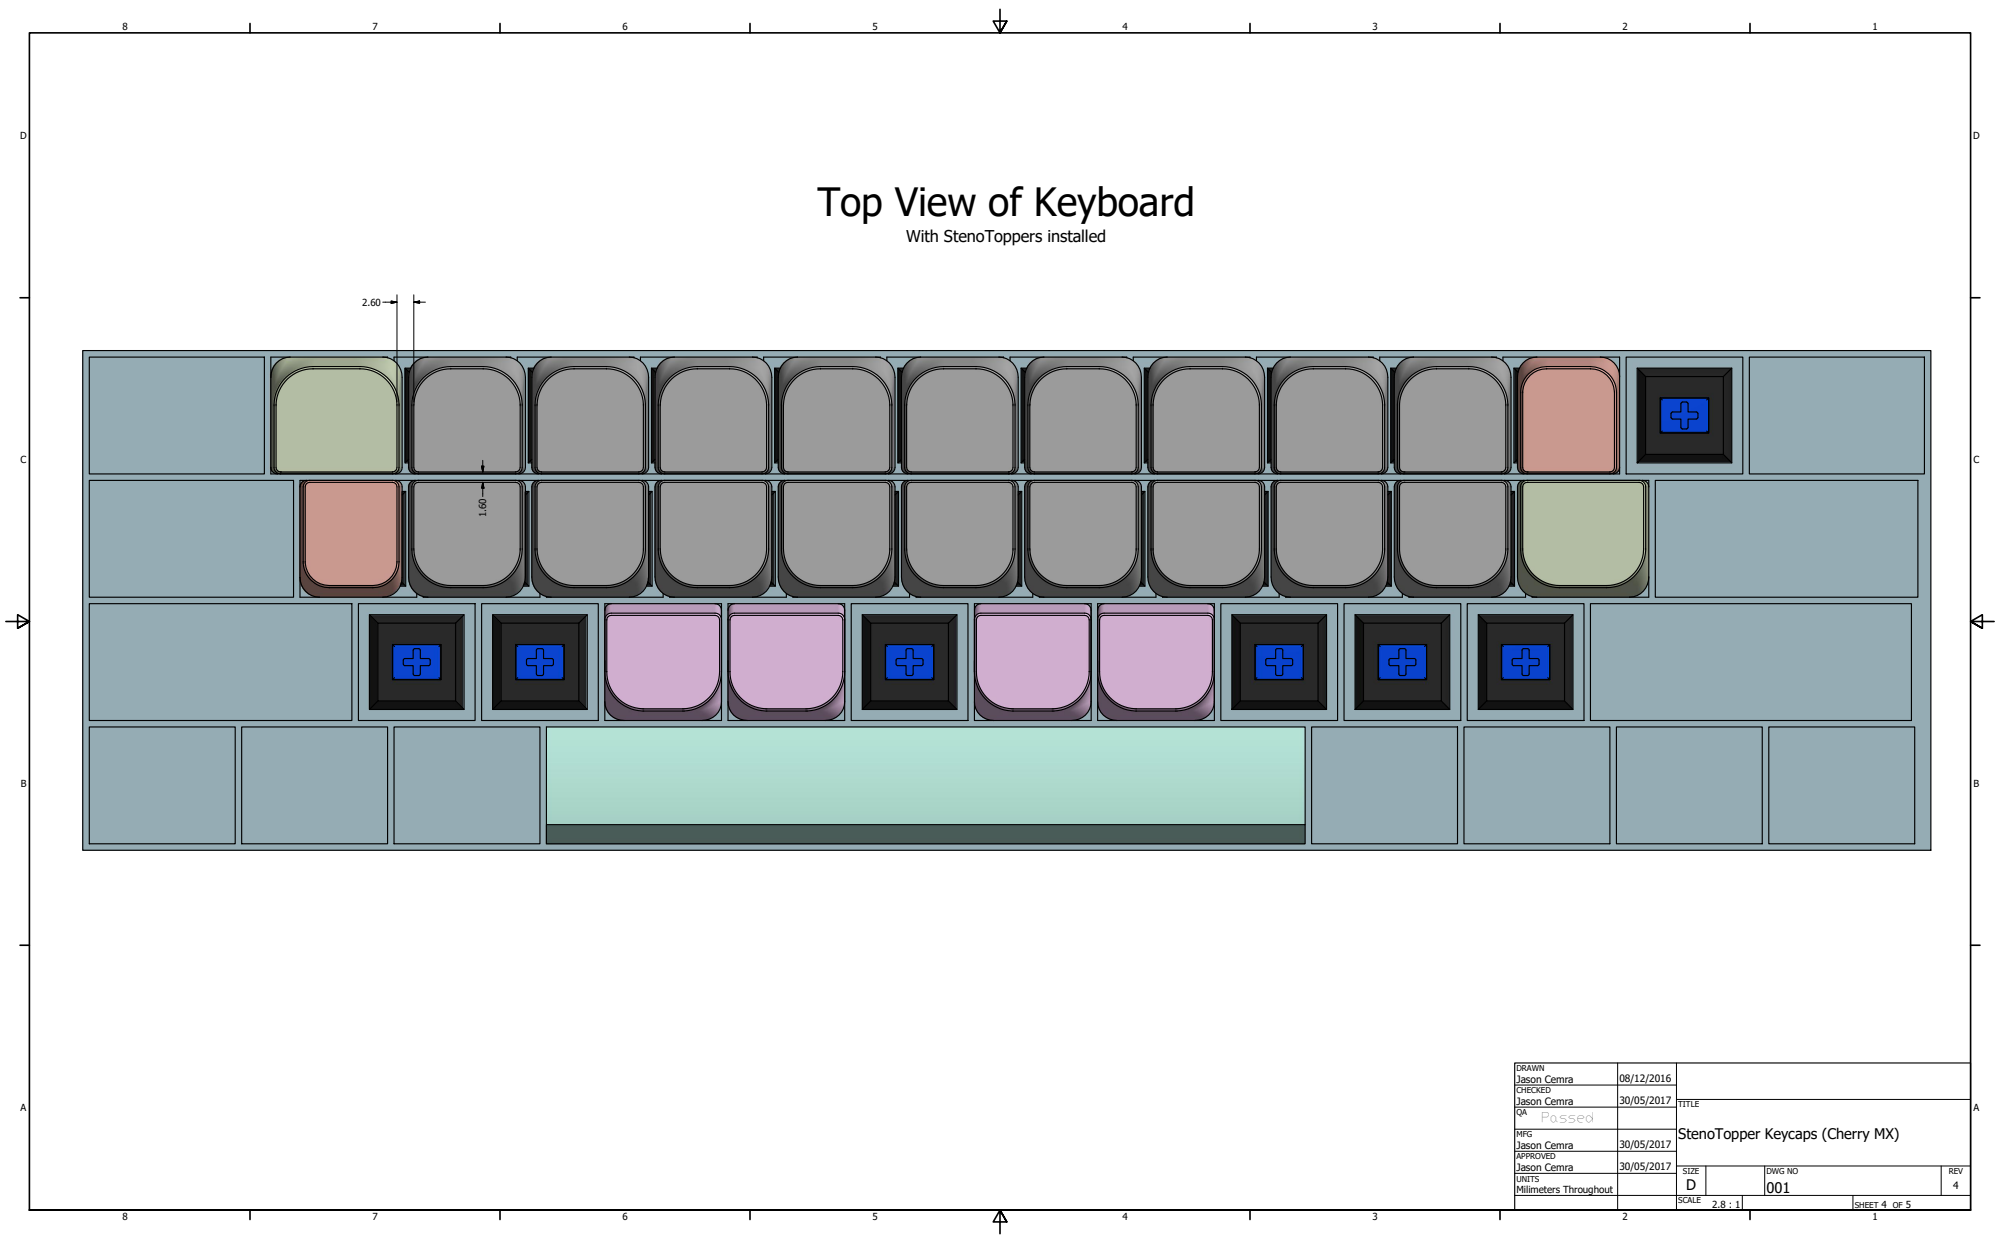
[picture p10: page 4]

Top View of Keyboard

With StenoToppers installed

DRAWN Jason Cemra | 08/12/2016

CHECKED Jason Cemra | 30/05/2017

TITLE
StenoTopper Keycaps (Cherry MX)

QA Passed

MFG Jason Cemra | 30/05/2017

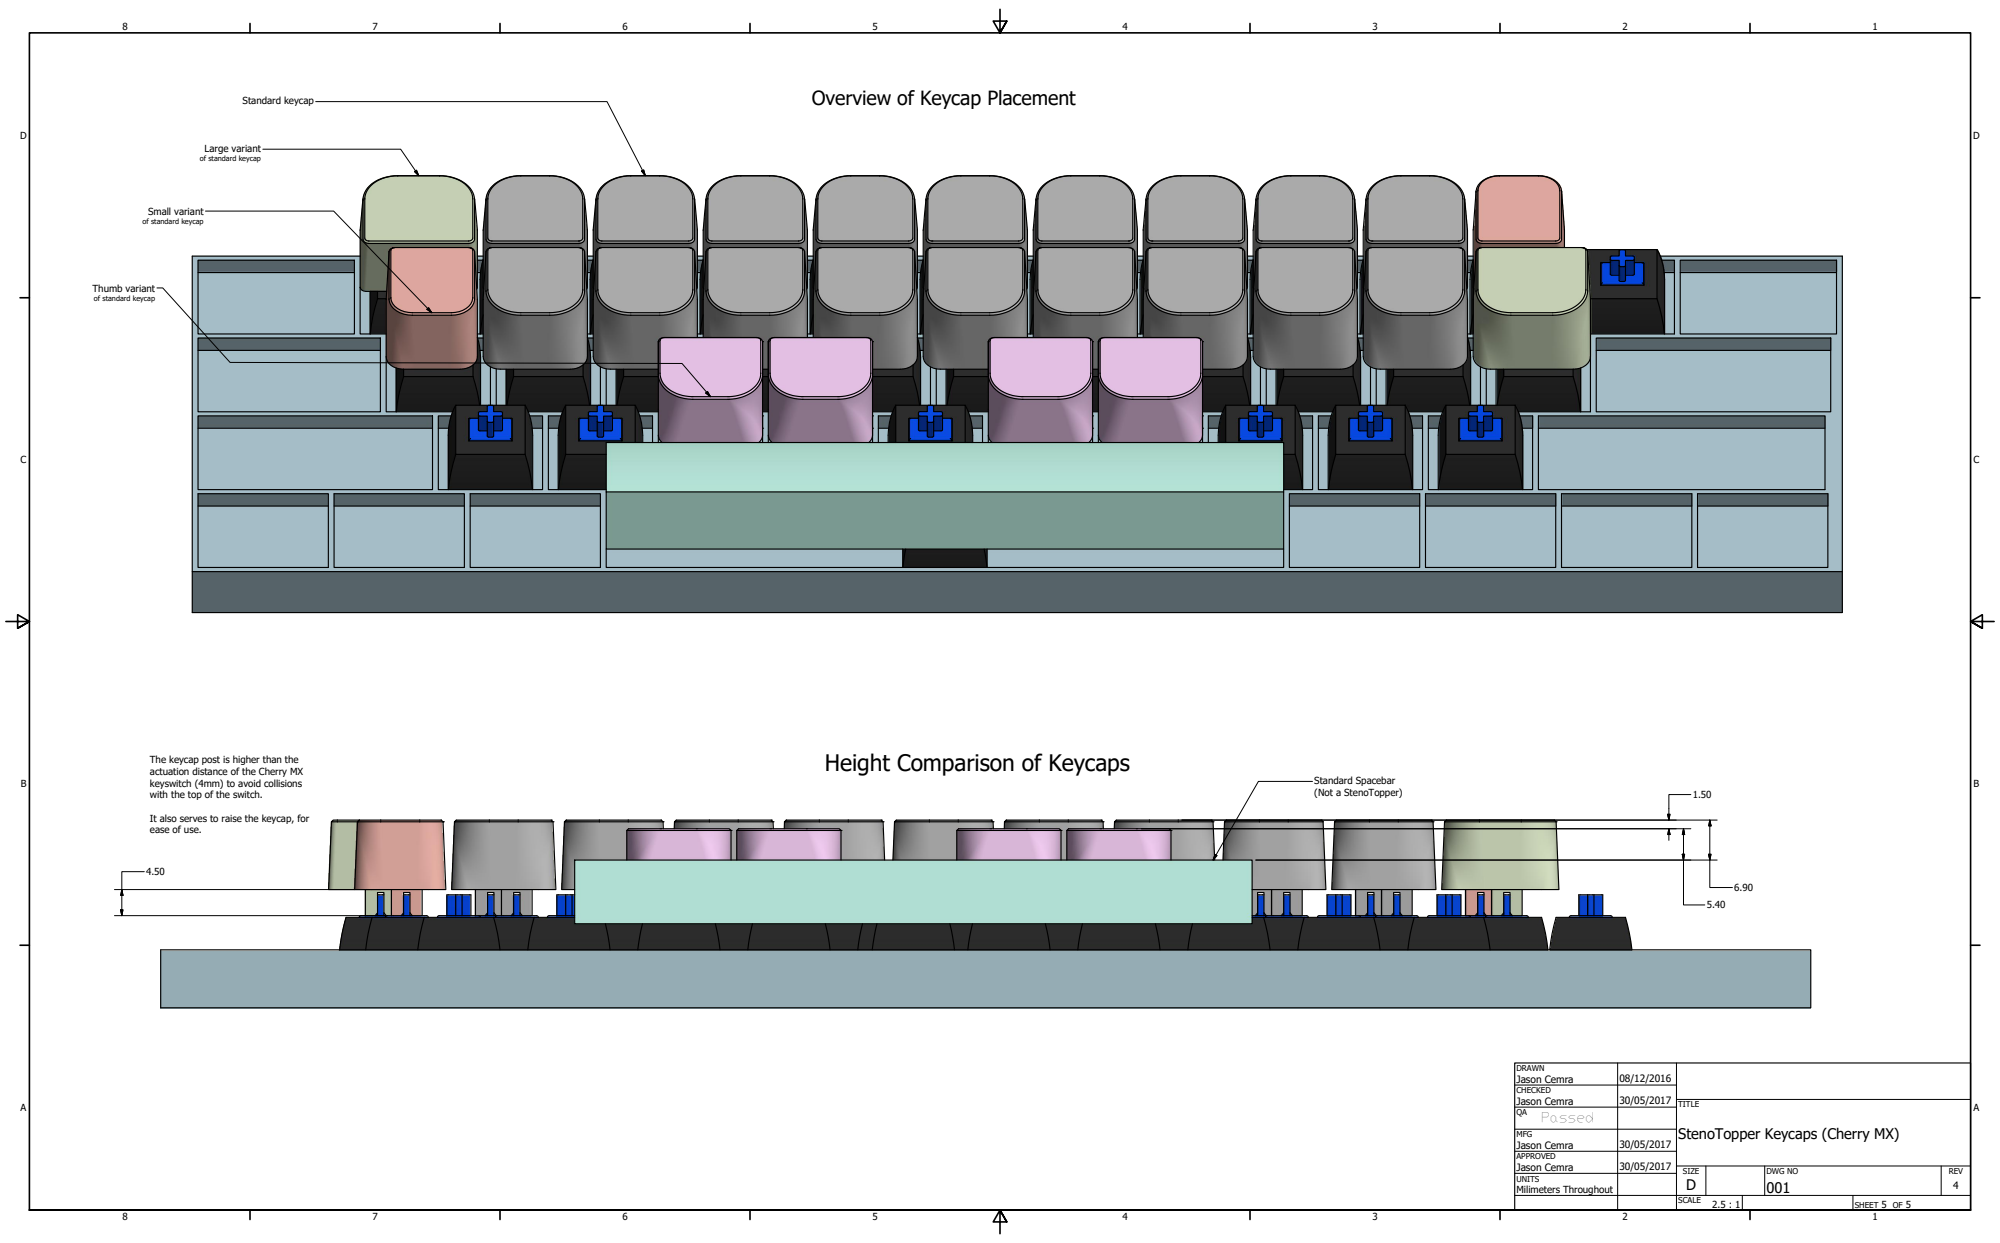
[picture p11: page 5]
Standard keycap; Overview of Keycap Placement; Standard Spacebar (Not a StenoTopper)

Large variant
of standard keycap

Small variant

Thumb variant

Height Comparison of Keycaps

The keycap post is higher than the
actuation distance of the Cherry MX
keyswitch (4mm) to avoid collisions
with the top of the switch.

It also serves to raise the keycap, for
ease of use.

DRAWN Jason Cemra | 08/12/2016

CHECKED Jason Cemra | 30/05/2017

TITLE
StenoTopper Keycaps (Cherry MX)

QA Passed

MFG Jason Cemra | 30/05/2017

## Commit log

2016-12-08 Base model (unmeasured) of standard keycap
    [standard-keycap_top-rows_base_cherrymx.ipt]
2016-12-08 Cherry MX keyswitch models (unmeasured) complete
    [keyswitch-base_cherrymx.ipt, keyswitch-pole_cherrymx.ipt]
2016-12-08 Updates to keyswitch models
    [keyswitch-base_cherrymx.ipt, keyswitch-pole_cherrymx.ipt]
2016-12-08 Changes to keyswitch, added keyboard mockup
    The keyboard mockup is unmeasured so far. It will be used to make
    the "StenoToppers" layout mockup in the future.
    [keyboard-mockup_cherrymx.iam, keyswitch_cherrymx.iam]
2016-12-08 Added a keyboard base
    [keyboard-base_standard.ipt]
2016-12-08 Updates to keyboard mockup and keyswitches
    [keyboard-mockup_cherrymx.iam, keyswitch-base_cherrymx.ipt, keyswitch-pole_cherrymx.ipt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]
2016-12-08 Modified the offset for the standard keycap
    I will need to pull project parameters out into a spreadsheet.
    This should happen soon.
    [standard-keycap_top-rows_base_cherrymx.ipt]
2016-12-08 Added a populated keyboard demo for StenoToppers!
    [populated-keyboard_cherrymx.iam]
2016-12-09 Made a start on a global parameters file
    [parameters.xlsx]
2016-12-09 Linked keyswitch components into parameters file
    [keyswitch-base_cherrymx.ipt, keyswitch-pole_cherrymx.ipt, keyswitch_cherrymx.iam]
2016-12-09 Linked standard keycap into parameters file
    [standard-keycap_top-rows_base_cherrymx.ipt]
2016-12-09 Added chamfer to pole base
    This will assist with placing the keycap over the keyswitch pole.
    [standard-keycap_top-rows_base_cherrymx.ipt]
2016-12-09 Added further parameters and calculations for the board
    [parameters.xlsx]
2016-12-09 Added spacebar-row to keyboard mockup
    [keyboard-base_standard.ipt]
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2016-12-09 Updates to populated keyboard mockup
    [populated-keyboard_cherrymx.iam]
2016-12-09 Made row offset very precise (for keycaps)
    [keyboard-mockup_cherrymx.iam, standard-keycap_top-rows_base_cherrymx.ipt]
2016-12-09 Added a smaller keycap variant
    [parameters.xlsx, smaller-keycap_top-rows_base_cherrymx.ipt]
2016-12-10 Added larger keycap and placed on keyboard
    Reviewing the smaller and larger keycaps, everything seems to fit
    properly. Checking my keyboard, there seems to be no collisions with
    keyswitches. We may add to the keycap pole to provide raising for the
    top rows and relatively lower the thumb keys.
    Also color coded some parts to make comparison easier.
    [keyboard-base_standard.ipt, keyboard-mockup_cherrymx.iam, keyswitch-base_cherrymx.ipt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]
2016-12-10 Added a preliminary drawing of the keycap
    [standard-keycap_top-rows_base_cherrymx_drawing.idw]
2016-12-10 More additions to the keycap drawings
    Also, moved drawings (and their pdf exports) to a "drawings" folder.
    May need to add subfolders if there are too many '.idw' files.
    [standard-keycap_top-rows_base_cherrymx_drawing.idw]
2016-12-10 Improvements to CAD Drawings
    [standard-keycap_top-rows_base_cherrymx_drawing.idw]
2016-12-10 Added a spacebar mockup (for thumb clearance comparison)
    [parameters.xlsx, spacebar-keycap_mockup_cherrymx.ipt]
2016-12-10 Added thumb keycap and updated keyboard
    [keyboard-base_standard.ipt, keyboard-mockup_cherrymx.iam, keyswitch-base_cherrymx.ipt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]
2016-12-10 Updated CAD drawing and added height profile comparison
    [standard-keycap_top-rows_base_cherrymx_drawing.idw]
2016-12-10 Made keycaps taller (for clearance)
    [keyboard-base_standard.ipt, keyswitch-base_cherrymx.ipt, keyswitch-pole_cherrymx.ipt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]
2016-12-11 Fixed spacing issue in drawing
    [standard-keycap_top-rows_base_cherrymx_drawing.idw]
2016-12-11 Attempted to implement iPart (failure?)
    iParts don't seem to do all the things I need for the variations. This
    is a pretty small project anyway, so the added complexity just isn't
    worth it. I already have a spreadsheet set up, so parameter changes
    shouldn't be too hard. iParts cause problems with materials and the
    thumb keycap.
    Calling it a failure and leaving it here. Maybe I'll come back? I doubt
    it.
    [keyboard-base_standard.ipt, keyboard-mockup_cherrymx.iam, keyswitch-base_cherrymx.ipt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]
2016-12-13 Made a working iPart setup
    Researched into iParts more and found ways to get a single base-keycap
    file. I will need to restructure the project in future and update the
    conventions document.
    Also restructured the base-model directory (cleaner now).
    I guess we're using iParts after all (thanks TFI!).
    [base-keycap.ipt, keyboard-base_standard.ipt, keyboard-mockup_cherrymx.iam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]
2016-12-13 Fixed oversized radius of smaller variant keycap
    [base-keycap.ipt, smaller_cmx.ipt]
2016-12-13 Fixed minor placement error in keyboard mockup
    [populated-keyboard_cherrymx.iam]
2016-12-13 Updated drawing to use iParts
    [base-keycap_cherrymx.idw, standard-keycap_top-rows_base_cherrymx_drawing.idw]
2016-12-13 Added model name as key column (in base-keycap iPart file)
    [base-keycap.ipt]
2016-12-13 Updated drawing dimensions (slight error)
    [base-keycap.ipt, base-keycap_cherrymx.idw, keyboard-base_standard.ipt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]
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2016-12-14 Removed mention of backlit design
    If you need your steno keyboard backlit, you're probably doing it wrong
    :P. Also, this variant will *double* the models needed, which is a
    maintenance cost that isn't currently worth it.
2016-12-14 Added 0.25mm clearance on CMX pole
    [base-keycap.ipt, base-keycap_cherrymx.idw, keyboard-base_standard.ipt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]
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2016-12-14 Project restructure and simplification
    I have decided to ditch all the variations of the stenotopper. Rather,
    there will be *one* stenotopper that is easily customizeable.
    This greatly simplifies develpment and is good enough for my purposes.
    There are still minor changes (and some potentially troublesome
    geometry) to fix up, but otherwise, this represents the final form of
    the stenotopper.
    [base-keycap.ipt, base-keycap_cherrymx.idw, keyboard-base_standard.ipt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]
2016-12-14 Adjusted Cut Depth for Cross
    [base-keycap_cherrymx.idw, larger_cmx.ipt, populated-keyboard_cherrymx.iam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]
2016-12-14 Relinked files to the parameters spreadsheet
    [base-keycap_cherrymx.idw, keyboard-base_standard.ipt, keyboard-mockup_cherrymx.iam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]
2016-12-15 Added pole height, shortened keycap
    To prevent collisions between the keycap skirt and the keyswitch, the
    actual keycap section was foreshortened. This shouldn't really change
    the aesthetic of the keycaps, because they're so tall, but that's the
    least of our concerns.
    The wall thickness of the pole is 0.4mm too thin - we'll see if this can
    be rectified without causing clearance issues with the keyswitch. If
    not, we may need to print forks instead of a pole - which will be
    equally interesting.
    Also, found a bug in Inventor that meant I had to set the capOffset of
    the thumb variant to 0.001 instead of 0 - otherwise, direction was not
    preserved (a big problem).
    [base-keycap_cherrymx.idw, keyboard-base_standard.ipt, keyboard-mockup_cherrymx.iam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]
2016-12-15 Added an aesthetic chamfer to the top face
    [larger_cmx.ipt, populated-keyboard_cherrymx.iam, smaller_cmx.ipt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]
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2016-12-15 Added a demo image and view for Inventor
    [stenotoppers.ipt]
2016-12-15 Updated some broken assembly data (fixed)
    [larger_cmx.ipt, populated-keyboard_cherrymx.iam, smaller_cmx.ipt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]
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2016-12-17 Major change to Cherry MX pole design
    The new design should work (in theory) *and* be much easier to 3D print.
    The traditional design has walls that are far too thin - not ideal.
    Also uprgaded the ribbing to have a slight draft angle, for strength
    reasons.
    NOTE: The design may also change in the future to incorporate walls on
    the long side of the keyswitch. This could potentially improve the
    strength of the model, but we'll see how it holds up without. Not adding
    until a test print because it could cause problems with clearances on
    the keyswitch.
    [larger_cmx.ipt, smaller_cmx.ipt, standard_cmx.ipt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]
2016-12-19 Decreased the cut-in depth to improve strength of part
    [larger_cmx.ipt, parameters.xlsx, smaller_cmx.ipt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]
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2016-12-19 Removed stress analysis because it was cluttering up the repository
    [larger_cmx.ipt, smaller_cmx.ipt, standard_cmx.ipt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]
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2017-01-04 Verified Dimensions against physical switches
    Very slight adjustments were made to the dimensions that I believe will
    improve the fit of the keycap to the switch. Also, the cut-in depth was
    reduced, which will increase the strength with marginal extra print
    time.
    The project is almost complete - all that's left is to do test prints
    and mark it off as finished!
    [base-keycap_cherrymx.idw, keyboard-base_standard.ipt, keyboard-mockup_cherrymx.iam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]
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2017-03-02 Adjusted measurements
    Now there's less clearance on the stem, so the keys should fit quite
    tightly. Each keyboard is different however, so I'll have to make a note
    of this for thourough testing.
    Also removed some tapers and gave the keys a tiny bit more breathing
    room.
    [keyboard-base_standard.ipt, keyboard-mockup_cherrymx.iam, keyswitch-base_cherrymx.ipt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]
2017-03-03 Increased decimation resolution (hopefully resolves print artifacts)
2017-03-03 Generated assemblies and STL files from ipt and iam
    [final-print.iam, keyboard-base_standard.ipt, keyboard-mockup_cherrymx.iam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]
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2017-05-31 New Updates (v1.0.0)
    Updates to drawings and models, read for full release!
    [base-keycap_cherrymx.idw, keyboard-base_standard.ipt, keyboard-mockup_cherrymx.iam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]
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
